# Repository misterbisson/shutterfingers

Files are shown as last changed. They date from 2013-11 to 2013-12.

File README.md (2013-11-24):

shutterfingers
==============

Listen to remote shutter signals on an [EOS-type 2.5mm TRS input](http://www.doc-diy.net/photo/eos_wired_remote/) and operate a servo to mechanically depress the shutter button for cameras that don't support such remote control.

See more at http://maisonbisson.com/post/17154/shutterfingers/

[Version 1](https://github.com/misterbisson/shutterfingers/releases/tag/1.0) and earlier were written for ATmega328 and ATmega32U4 Arduino environments (the classic Arduino Uno and Leonardo, and similar).

Later versions are refactored for ATtiny85 running on a [Digispark board](http://digistump.com/products/1), because anything bigger is overkill. Also, because it's way cheaper.

The [parts list is here](https://github.com/misterbisson/shutterfingers/blob/master/hardware/v2/README.md), and schematic is available as [PNG](https://github.com/misterbisson/shutterfingers/blob/master/hardware/v2/shutterfingers.png) or [Fritzing file](https://github.com/misterbisson/shutterfingers/blob/master/hardware/v2/shutterfingers.fzz). The [Fritzing app](http://fritzing.org/download/) is a free (GPL free) download.

This software is [provided under the terms of the GPL v2](https://github.com/misterbisson/shutterfingers/blob/master/LICENSE.txt).

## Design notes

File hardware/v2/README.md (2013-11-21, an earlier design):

#### Bill of materials ####

1. [Digispark](http://digistump.com/products/1)
1. [Digispark proto shield](http://digistump.com/products/2)
1. [sub-micro servo](https://www.sparkfun.com/products/9065)
1. [2.5mm panel mount TRS jack](http://www.radioshack.com/product/index.jsp?productId=2103450)
1. [LiPo battery, 400mAh](https://www.sparkfun.com/products/10718)
1. [LiPo charger/booster](https://www.sparkfun.com/products/11231)
1. [power switch](https://www.sparkfun.com/products/11975)
1. [RGB cycling LED](https://www.sparkfun.com/products/11449)
1. [hot shoe to 1/4 threaded adapter](http://www.amazon.com/dp/B0088VQEV2/)
1. [aluminum project box](http://www.amazon.com/gp/product/B0002BBQYG/)

#### Fritzing parts libray ####
Digispark.fzpz is pretty well hidden on the internetz. I’ve included a copy here, but it was originally downloaded from [an attachment](https://fritzing.googlecode.com/issues/attachment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) to [an issue](https://code.google.com/p/fritzing/issues/detail?id=2753) in the Google code repo for Fritzing and hasn’t yet been added to the core parts library.

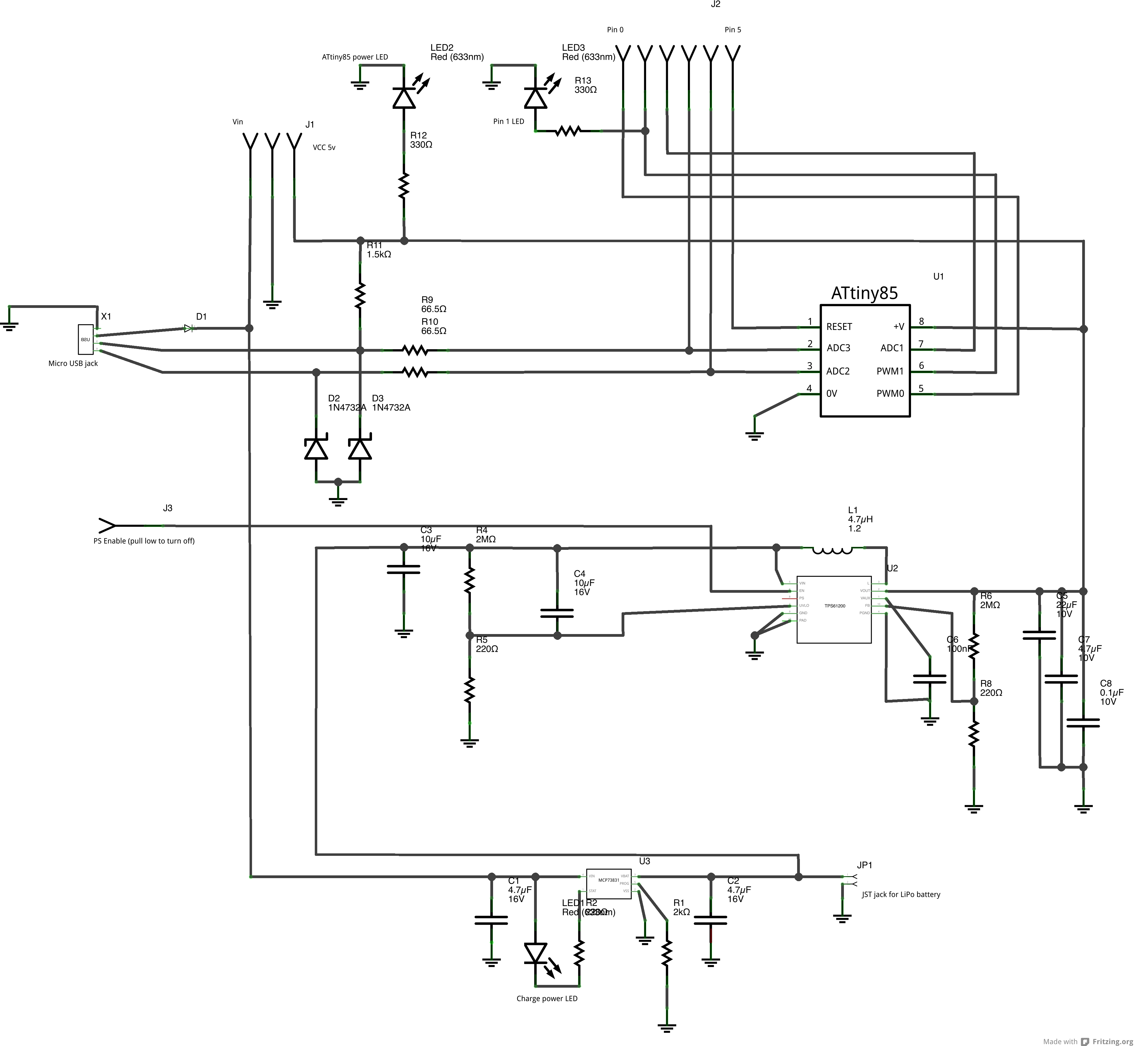
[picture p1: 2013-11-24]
hardware/v3/LiPoSpark.png

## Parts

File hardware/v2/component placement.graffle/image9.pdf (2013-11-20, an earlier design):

1.1420
[29,007]

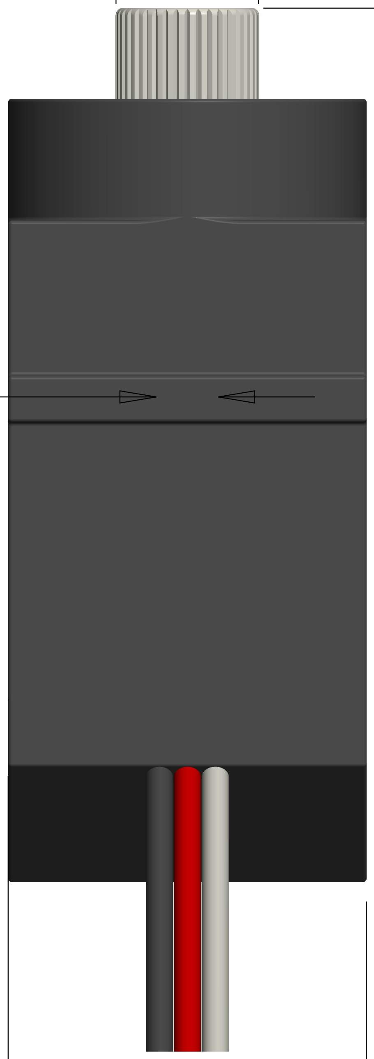
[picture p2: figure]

.4620
[11,735]

.1838
[4,668]

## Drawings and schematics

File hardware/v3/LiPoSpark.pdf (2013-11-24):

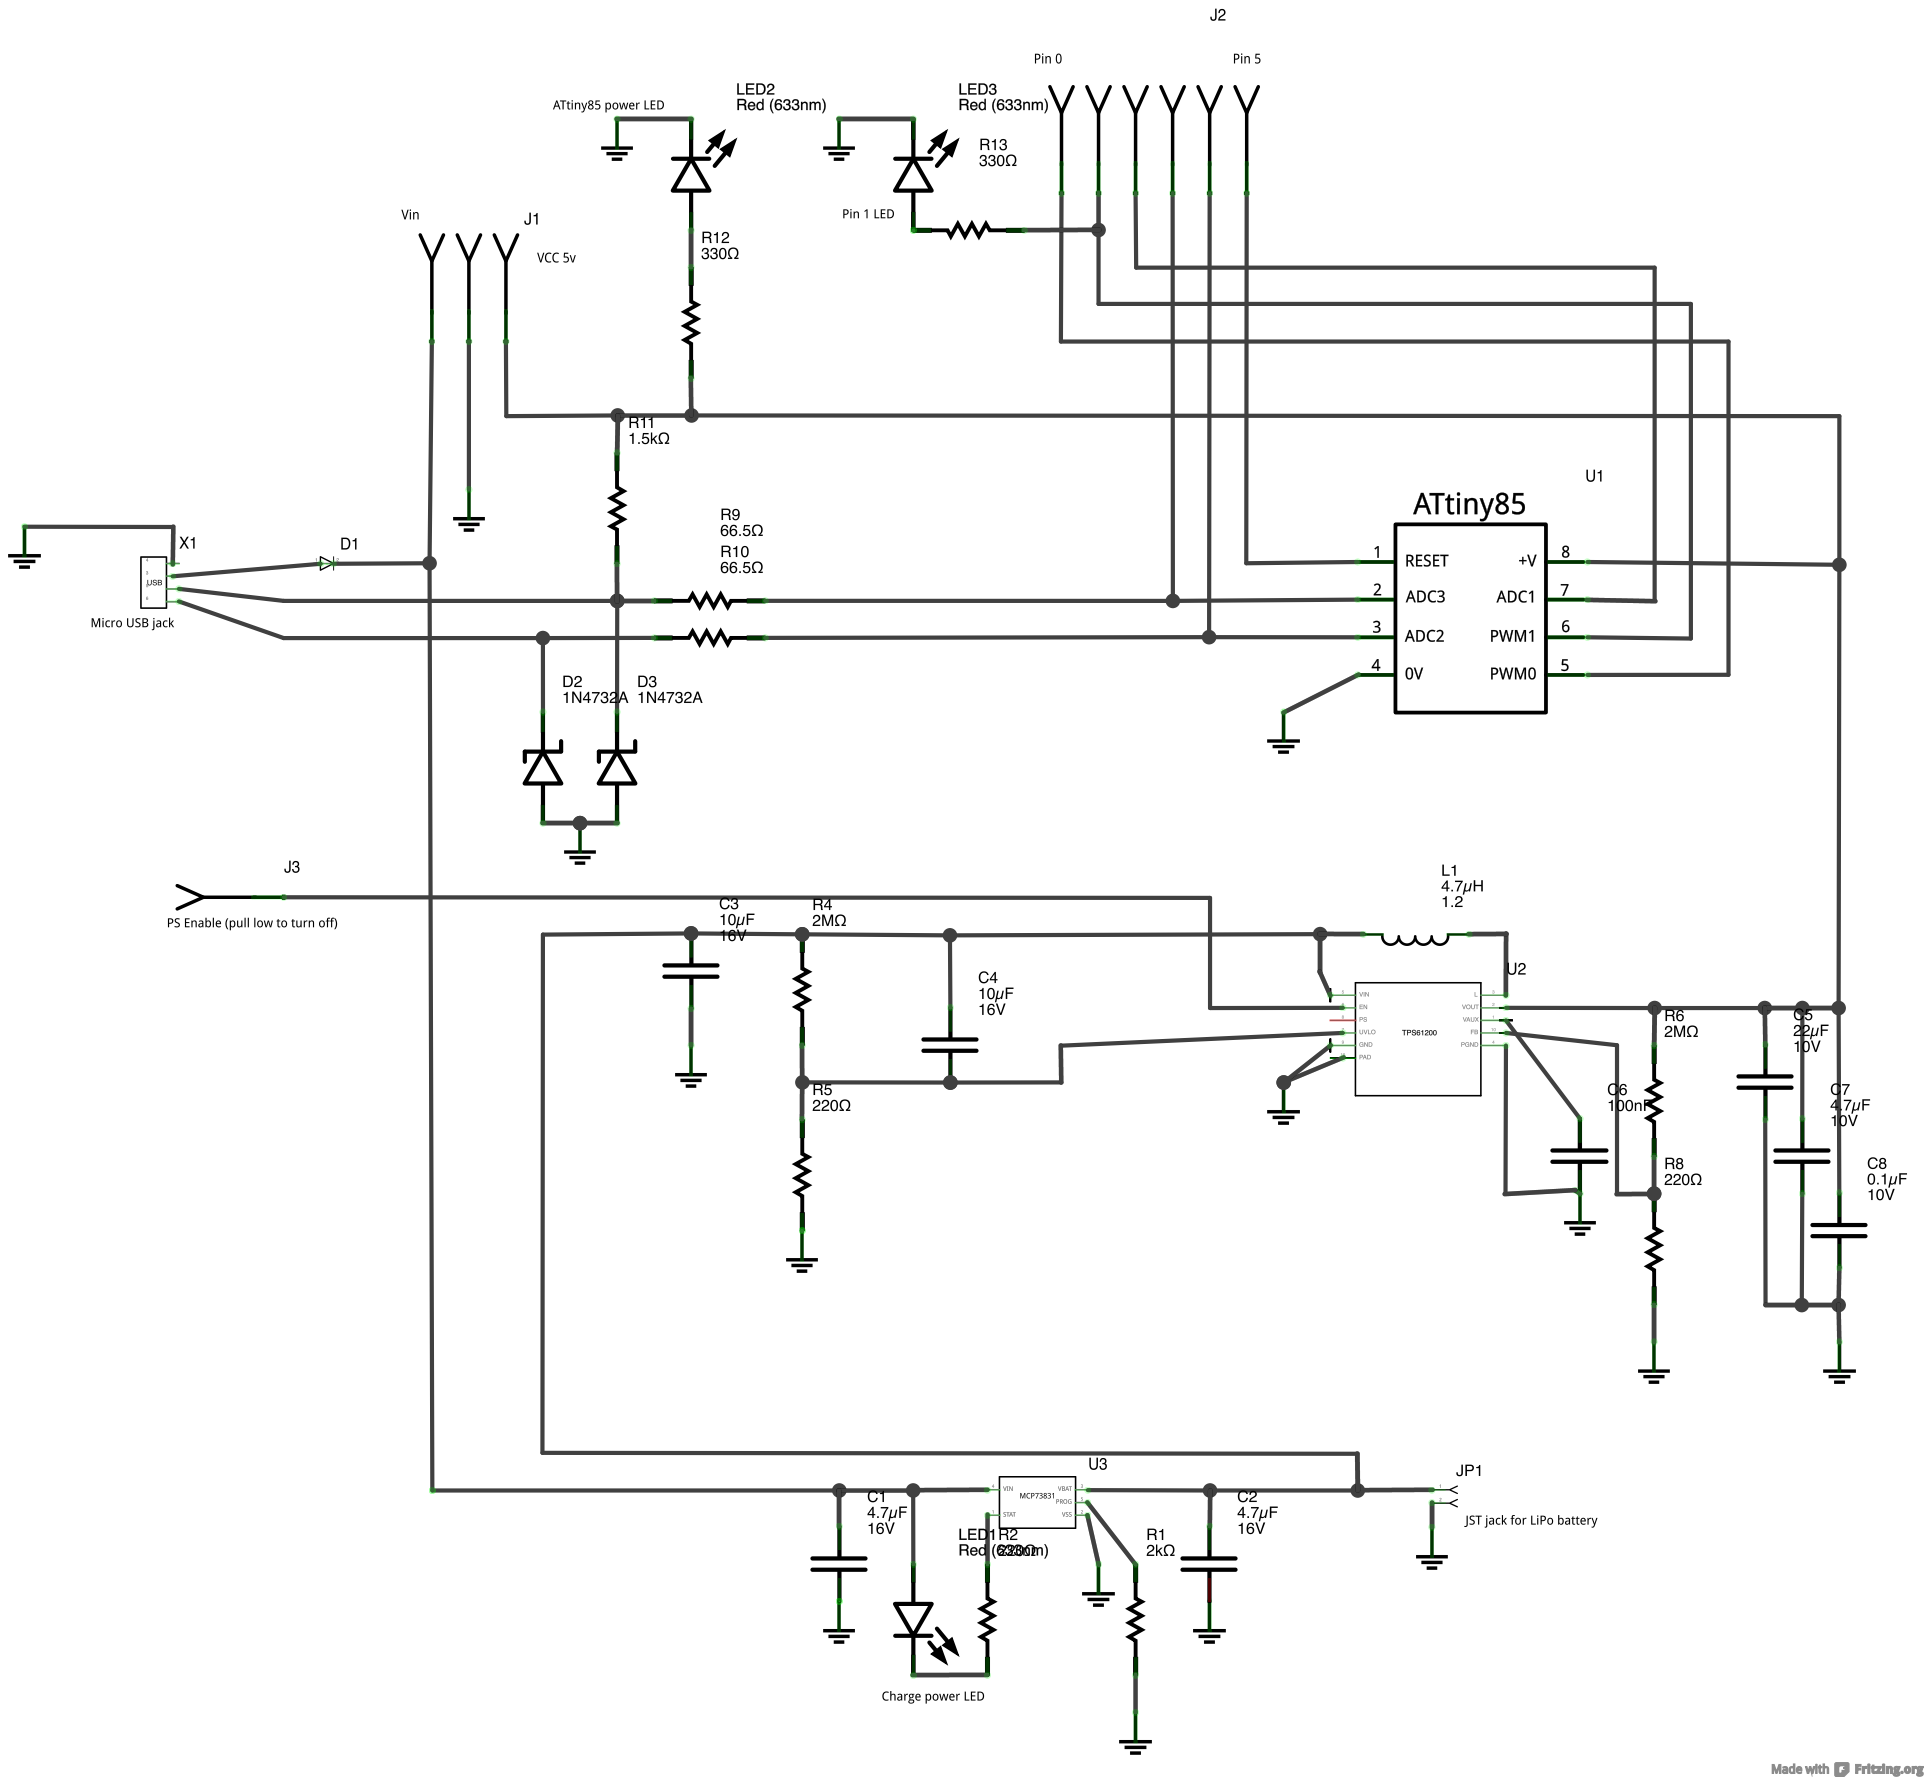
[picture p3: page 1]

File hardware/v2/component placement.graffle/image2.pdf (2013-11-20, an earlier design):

## SECTION B-B Side View of Assembly

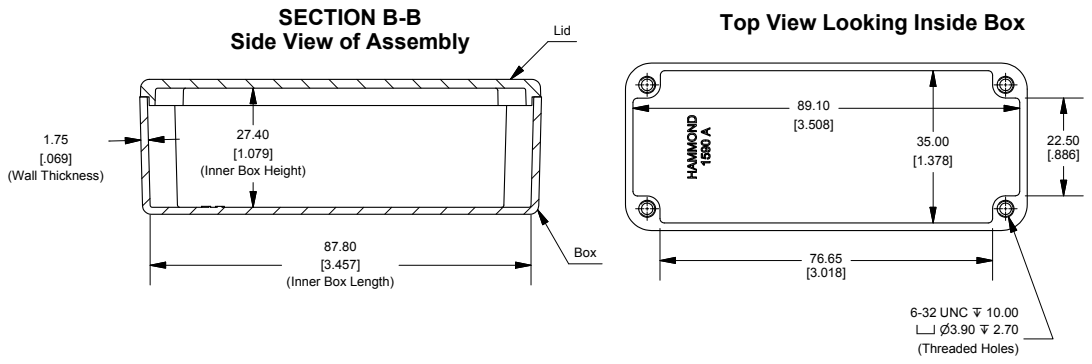
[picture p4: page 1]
27.40 [1.079] (Inner Box Height); 87.80 [3.457] (Inner Box Length); Lid; Box; 6-32 UNC; (Threaded Holes); 1.75 [.069] (Wall Thickness)

Top View Looking Inside Box

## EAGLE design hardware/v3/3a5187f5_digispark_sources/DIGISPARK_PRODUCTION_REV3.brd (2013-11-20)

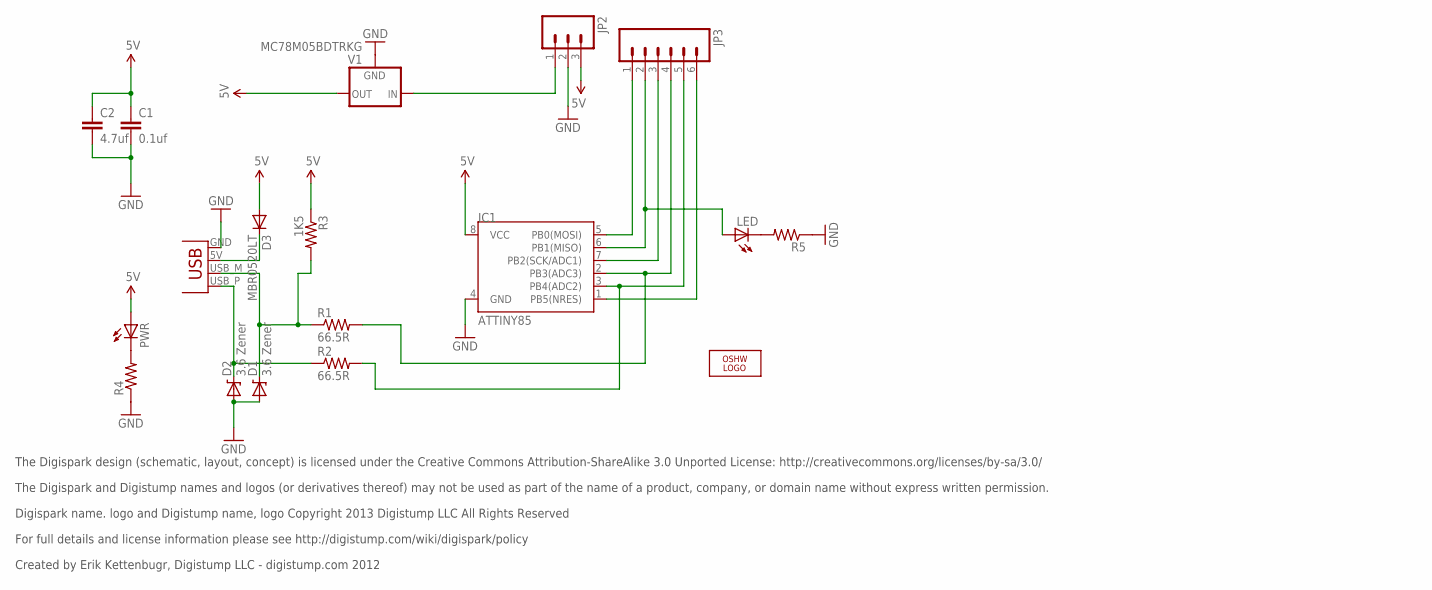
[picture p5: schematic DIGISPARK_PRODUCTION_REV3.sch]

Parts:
C1: 0.1uf; 0402-CAP
C2: 4.7uf; 0805
D1, D2: 3.6 Zener; SOD-323
D3: MBR0520LT; SOD123
IC1: ATTINY85; SO08-EIAJ
JP2: M03PTH; 1X03
JP3: M06SIP; 1X06
LED: LED0603; LED-0603
LOGO2: LOGO-OSHW-10MILX0200-NT; OSHW_10X200_NOTEXT
PWR: LED0603; LED-0603
R1, R2: 66.5R; 0402-RES
R3: 1K5; 0402-RES
R4, R5: RESISTOR0402-RES; 0402-RES
V1: MC78M05BDTRKG; DPACK
X1: USBPCB; USB-A-PCB

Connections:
5V: C1.1, C2.1, D3.A, IC1.8 (VCC), JP2.3, PWR.A, R3.1, V1.3 (OUT)
GND: C1.2, C2.2, D1.2 (A), D2.2 (A), IC1.4 (GND), JP2.2, R4.1, R5.1, V1.4 (GND), X1.GND
unnamed: IC1.2 (PB3(ADC3)), JP3.4, R1.2
unnamed: IC1.6 (PB1(MISO)), JP3.2, LED.A
unnamed: IC1.5 (PB0(MOSI)), JP3.1
unnamed: IC1.7 (PB2(SCK/ADC1)), JP3.3
unnamed: IC1.3 (PB4(ADC2)), JP3.5, R2.2
unnamed: IC1.1 (PB5(NRES)), JP3.6
unnamed: D1.1 (C), R1.1, R3.2, X1.USB_M (D-)
unnamed: D2.1 (C), R2.1, X1.USB_P (D+)
unnamed: LED.C, R5.2
unnamed: JP2.1, V1.1 (IN)
unnamed: D3.C, X1.5V (VBUS)
unnamed: PWR.C, R4.2

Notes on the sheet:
The Digispark design (schematic, layout, concept) is licensed under the Creative Commons Attribution-ShareAlike 3.0 Unported License: http://creativecommons.org/licenses/by-sa/3.0/
The Digispark and Digistump names and logos (or derivatives thereof) may not be used as part of the name of a product, company, or domain name without express written permission.
Digispark name. logo and Digistump name, logo Copyright 2013 Digistump LLC All Rights Reserved
For full details and license information please see http://digistump.com/wiki/digispark/policy
Created by Erik Kettenbugr, Digistump LLC - digistump.com 2012

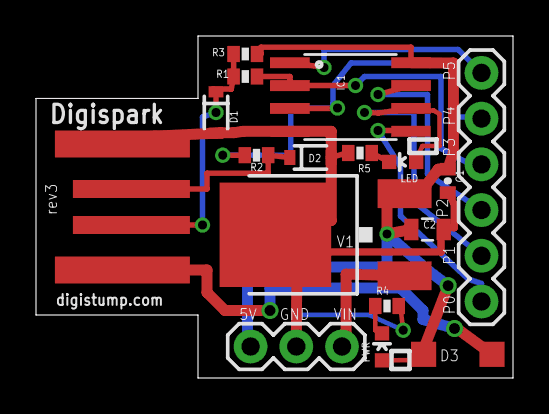
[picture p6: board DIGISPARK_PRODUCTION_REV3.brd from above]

Board: 2 copper layers, 26.5 x 19.0 mm, 18 parts (1 on the bottom side), 14 nets.

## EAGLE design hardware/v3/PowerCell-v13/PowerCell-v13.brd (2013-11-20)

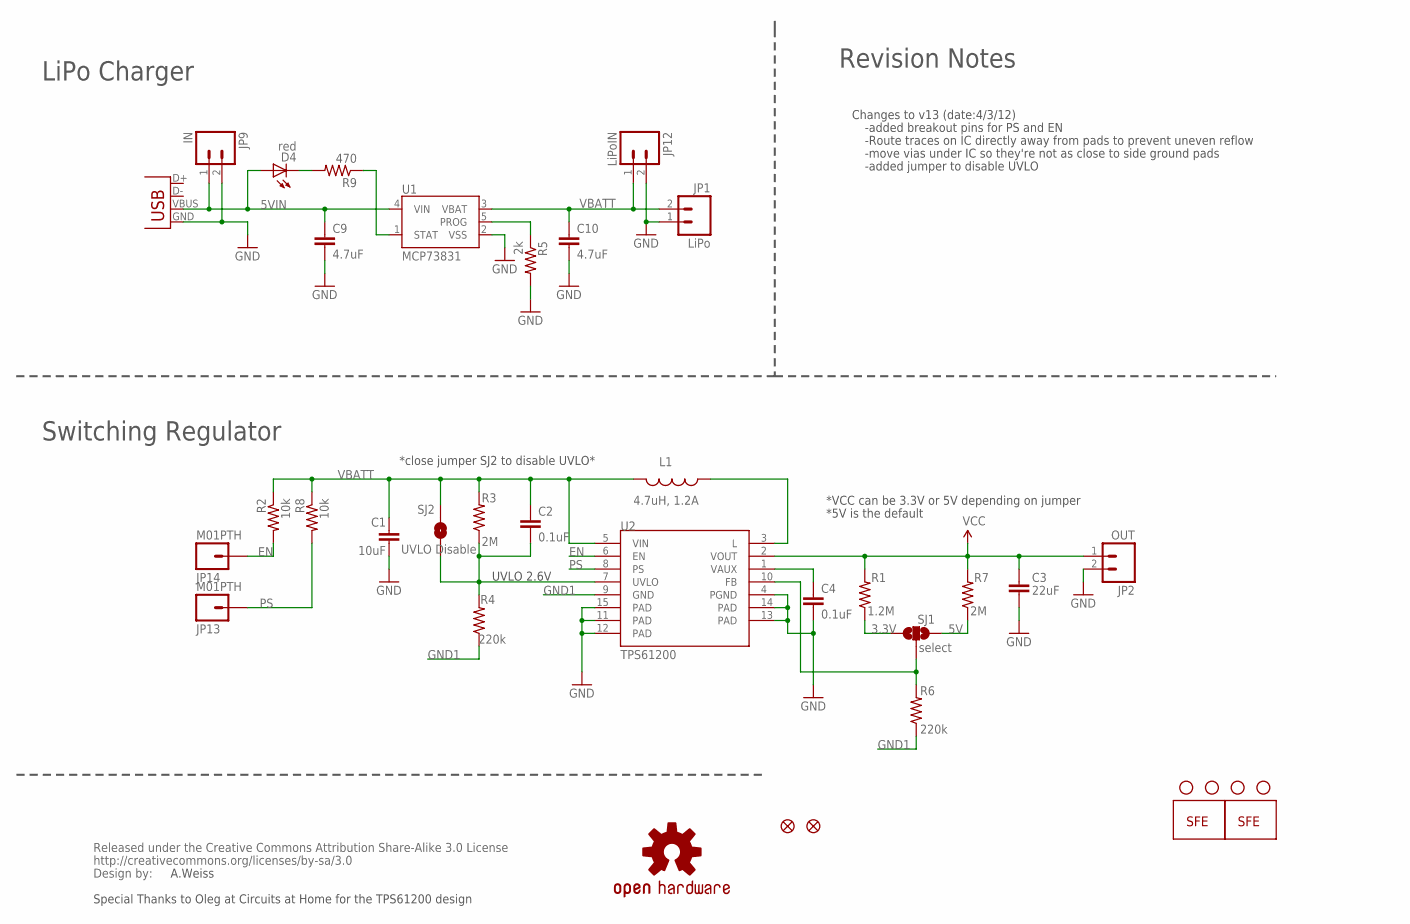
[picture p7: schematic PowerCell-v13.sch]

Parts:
C1: 10uF; 1206
C2, C4: 0.1uF; 0402-CAP
C3: 22uF; 0805
C9, C10: 4.7uF; 0402-CAP
D4: red; LED-0603
JP1: LiPo; JST-2-SMD
JP2: OUT; 1X02
JP3: LOGO-SFENEW; SFE-NEW-WEBLOGO
JP4: LOGO-SFESK; SFE-LOGO-FLAME
JP5, JP6, JP7, JP8: STAND-OFF
JP9: IN; 1X02
JP12: LiPoIN; 1X02
JP13, JP14: M01PTH; 1X01
JP15, JP16: FIDUCIALUFIDUCIAL; MICRO-FIDUCIAL
L1: 4.7uH, 1.2A; CDRH2D09
R1: 1.2M; 0402-RES
R2, R8: 10k; 0402-RES
R3, R7: 2M; 0402-RES
R4, R6: 220k; 0402-RES
R5: 2k; 0402-RES
R9: 470; 0402-RES
SJ1: select; SJ_3_PASTE2&3
SJ2: UVLO Disable; SJ_2S-NO
U1: MCP73831; SOT23-5
U2: TPS61200; QFN-10_PAD
U$1: OSHW-LOGOS; OSHW-LOGO-S
U$2: CREATIVE_COMMONS
X1: USB-MICROB

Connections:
3.3V: R1.1, SJ1.1
5V: R7.1, SJ1.3
5VIN: C9.1, D4.A, JP9.1, U1.4 (VIN), X1.VBUS
EN: JP14.1, R2.2, U2.6 (EN)
FB: R6.2, SJ1.2, U2.10 (FB)
GND: C1.2, C3.2, C4.2, C9.2, C10.2, JP1.1, JP2.2, JP9.2, JP12.2, R5.2, U1.2 (VSS), U2.4 (PGND), U2.11 (PAD), U2.12 (PAD), U2.13 (PAD), U2.14 (PAD), U2.15 (PAD), X1.GND
GND1: R4.1, R6.1, U2.9 (GND)
unnamed: C4.1, U2.1 (VAUX)
unnamed: L1.P$1 (1), U2.3 (L)
unnamed: D4.C, R9.2
unnamed: R5.1, U1.5 (PROG)
unnamed: R9.1, U1.1 (STAT)
PS: JP13.1, R8.2, U2.8 (PS)
UVLO: C2.2, R3.1, R4.2, SJ2.1, U2.7 (UVLO)
VBATT: C1.1, C2.1, C10.1, JP1.2, JP12.1, L1.P$2 (2), R2.1, R3.2, R8.1, SJ2.2, U1.3 (VBAT), U2.5 (VIN)
VCC: C3.1, JP2.1, R1.2, R7.2, U2.2 (VOUT)

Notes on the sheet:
UVLO 2.6V
Changes to v13 (date:4/3/12)
-added breakout pins for PS and EN
-Route traces on IC directly away from pads to prevent uneven reflow
-move vias under IC so they're not as close to side ground pads
*close jumper SJ2 to disable UVLO*
-added jumper to disable UVLO
A.Weiss
Special Thanks to Oleg at Circuits at Home for the TPS61200 design
LiPo Charger
Switching Regulator
Revision Notes
*VCC can be 3.3V or 5V depending on jumper
*5V is the default

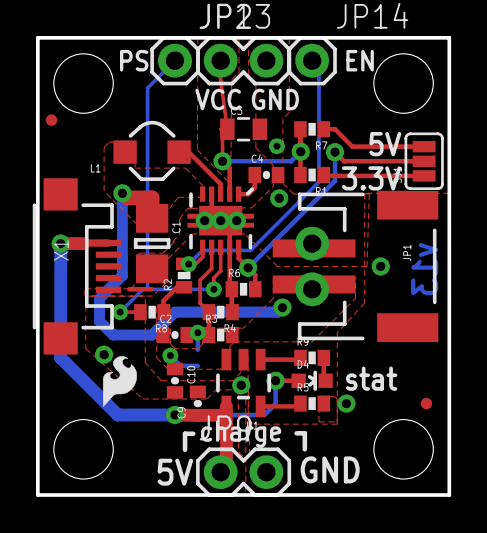
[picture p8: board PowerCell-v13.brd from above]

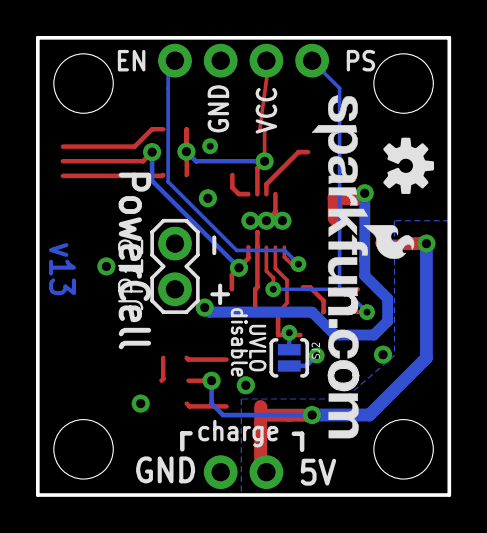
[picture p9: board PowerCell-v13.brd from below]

Board: 2 copper layers, 22.9 x 25.4 mm, 38 parts (4 on the bottom side), 16 nets.

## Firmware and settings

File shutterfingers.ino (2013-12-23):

/*
shutterfingers

Positions a servo to depress the shutter button of a camera when triggered
from a remote shutter release cable. See URL below for pinouts:
http://www.doc-diy.net/photo/eos_wired_remote/

This code is written for ATtiny85 running on a Digispark board.
See http://digistump.com/products/1

Version 1 of the project can was written for a more common ATmega328
or ATmega32U4-powered Arduino environment. It's still available from:
https://github.com/misterbisson/shutterfingers/releases

The ATtiny85 differs in a number if ways from ATmega328 and ATmega32U4 environments.
These two pages offer detail some of those differences:
https://learn.sparkfun.com/tutorials/tiny-avr-programmer-hookup-guide/attiny85-use-hints
http://digistump.com/wiki/digispark/tutorials/basics

Regarding pins usage and pull-up (pullup) resistors on the Digispark and ATtiny85:

Overview of pins, fromhttp://digistump.com/board/index.php/topic,986.0.html

	"P5 has a weak drive, current is limited to a few mA, high level voltage is 3V @1mA and 2.5V @2mA
	P4 is connected to a zener diode for USB, the internal pullup is too weak to set the pin to HIGH
	P3 has a 1.5KΩ pullup
	P0 or P1 (depending on model) is connected to the onboard led, which interferes with the internal pullup"

More about pins to avoid, from http://digistump.com/board/index.php/topic,1105.0.html

	"I was saying that P5 is weak and useless as an output because
	it's the reset pin and it's said in the datasheet you can't get a lot
	of current from it, voltage drops a lot when you drain even a few mAs."

	"if you want to keep USB feature, P3/P4 must be kept"

And quoting from http://digistump.com/wiki/digispark/tutorials/basics :

	"Pin 3 (P3) has a 1.5 kΩ pull-up resistor attached to it which is required for
	when P3 and P4 are used for USB communication (including programming). Your design
	may need to take into account that you'd have to overpower this to pull this pin low."

	"The internal pull-up resistor are much weaker (about 25 kohm) on an ATtiny
	than on an Arduino, so the onboard LED interferes with them. If you need them,
	you can use a different port. Change your circuit to not need the internal
	pull-up, or cut the LED trace."

And because I think there are some typos in the above description about using
the the internal pull-ups, I used the example in http://digistump.com/board/index.php/topic,1086.msg4553.html#msg4553
when implementing them in this project.
*/

/*
Trigger inputs, corresponding servo positions, and states
*/
const int safety_pos  = 45; // safety position for the servo, away from the shutter button

const int shutter_pin = 0;  // the number of the pushbutton pin
const int shutter_pos = 33; // position at which the camera's shutter is released
const int shutter_led = 1;  // the number of the LED pin
int shutter_state     = 0;  // variable for reading the pushbutton status

const int focus_pin   = 2;
const int focus_led   = 1;
const int focus_pos   = 37;
int focus_state       = 0;

int shutter_servo_state;

/*
Shutter servo details
Using Simple Servo here:
http://digistump.com/board/index.php/topic,444.0.html
https://github.com/digistump/DigisparkArduinoIntegration/tree/master/libraries/DigisparkSimpleServo

Alternatives (untested) include:
https://github.com/digistump/DigisparkArduinoIntegration/tree/master/libraries/DigisparkSoftRcPulseOut
https://github.com/fri000/Servo8Bit
*/
#include <SimpleServo.h>
SimpleServo shutter_servo;        // create servo object to control a servo
const int shutter_servo_pin = 5;  // pin on which the servo is attached


void setup()
{
  pinMode( shutter_pin, INPUT );
  digitalWrite( shutter_pin, HIGH ); // activate internal pull-up
  pinMode( shutter_led, OUTPUT );
  digitalWrite( shutter_led, LOW ); // not necessary, but we're setting so many other pins...

  pinMode( focus_pin, INPUT );
  digitalWrite( focus_pin, HIGH );
  pinMode( focus_led, OUTPUT );
  digitalWrite( focus_led, LOW );

  shutter_servo.attach( shutter_servo_pin );  // attaches the servo on the defined pin to the servo object
  shutter_servo.write( safety_pos );
  shutter_servo_state = safety_pos;
}

void loop()
{
  // read the inputs
  focus_state = digitalRead( focus_pin );
  shutter_state = digitalRead( shutter_pin );

  // determine where to send the servo
  // only reposition the servo if the new position is different from the previous
  if ( LOW == shutter_state )
  {
    if ( shutter_servo_state != shutter_pos )
    {
      shutter_servo.write( shutter_pos );
      digitalWrite( focus_led, LOW );
      digitalWrite( shutter_led, HIGH );
      shutter_servo_state = shutter_pos;
    }
  }
  else if ( LOW == focus_state )
  {
    if ( shutter_servo_state != focus_pos )
    {
      shutter_servo.write( focus_pos );
      digitalWrite( shutter_led, LOW );
      digitalWrite( focus_led, HIGH );
      shutter_servo_state = focus_pos;
    }
  }
  else
  {
    if ( shutter_servo_state != safety_pos )
    {
      shutter_servo.write( safety_pos );
      digitalWrite( shutter_led, LOW );
      digitalWrite( focus_led, LOW );
      shutter_servo_state = safety_pos;
    }
  }

  // sleep for some number of milliseconds, have some patience
  delay( 15 );
}

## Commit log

2013-08-31 important note added to the top: this code has never been run on an actual Arduino yet
2013-09-01 better cable info URL
2013-10-06 changed pin assignments, added second LED
2013-10-08 calibrated servo angles
2013-11-20 added hardware directory to track hardware design
    [DIGISPARK_PRODUCTION_REV3.brd, DIGISPARK_PRODUCTION_REV3.sch, PowerCell-v13.brd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]
2013-11-21 just one led_pin, using real tab stops
2013-11-21 spelling correction, added hardware bits
    [shutterfingers.ino]
2013-11-21 added fritzing sketch
    [shutterfingers.fzz]
2013-11-21 added schematic links.
2013-11-21 Added BOM
2013-11-21 Added missing link for 2.5mm TRS jack
2013-11-21 added link to BOM
2013-11-21 corrected pin locations
    [shutterfingers.fzz]
2013-11-21 corrected pin again
    [shutterfingers.fzz]
2013-11-23 added pin usage notes
    ...and moved the servo from 5 to 0 because pin 5 is supposedly "useless as an output"
    [shutterfingers.fzz]
2013-11-23 moved servo pin back
    ..because pin 5 isn't that useless
    also rearranged some bits
2013-11-24 fully working
    I'm not entirely clear why this version works and the previous version didn't (it was behaving like the focus pin was always pulled low).
    The changes that I'm aware of:
    1. Using spaces instead of real tabs for indents. Why does the Arduino IDE hate tabs?
    2. Eliminated use of `led_pin` and replaced it with separate `shutter_led` and `focus_led` constants, even though they point to the exact same pin definition.
    3. `safety_pos` constant is defined earlier, and a few other things are slightly moved around.
    [shutterfingers.ino]
2013-11-24 added v3 schematic
    ...for Digispark with integrated LiPo charger and power booster
    A marriage of the following:
    https://s3.amazonaws.com/digistump-resources/files/97a1bb28_DigisparkSchematic.pdf
    http://dlnmh9ip6v2uc.cloudfront.net/datasheets/Prototyping/PowerCell-v13.pdf (from https://www.sparkfun.com/products/11231)
    [LiPoSpark.fzz]
2013-12-23 changed servo positions

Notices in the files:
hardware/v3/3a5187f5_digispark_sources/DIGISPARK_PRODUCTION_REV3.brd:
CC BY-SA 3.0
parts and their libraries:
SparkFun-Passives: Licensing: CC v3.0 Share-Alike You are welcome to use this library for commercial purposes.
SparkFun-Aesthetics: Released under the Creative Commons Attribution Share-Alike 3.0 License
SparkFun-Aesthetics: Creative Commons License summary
